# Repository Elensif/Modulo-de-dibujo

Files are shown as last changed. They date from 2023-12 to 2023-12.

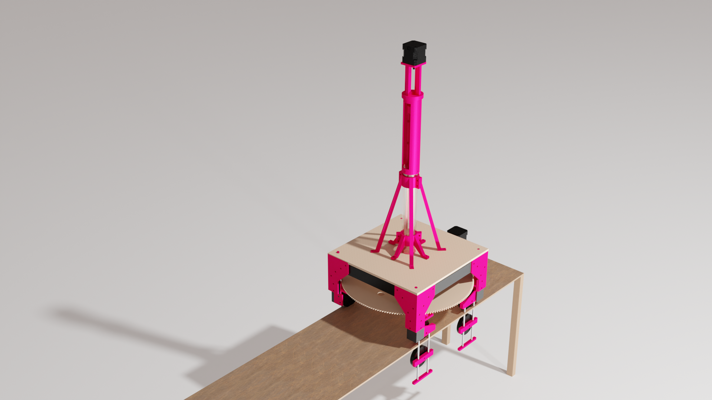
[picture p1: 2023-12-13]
Modelos 3D/Fotografías/1. Diseño prototipo.png

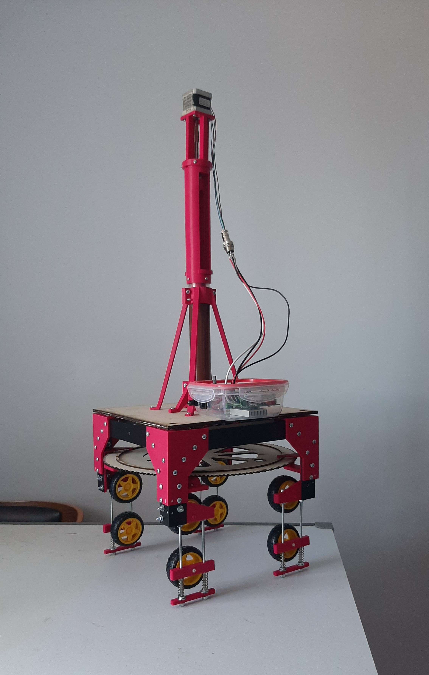
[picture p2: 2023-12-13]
Modelos 3D/Fotografías/2. Prototipo armado.jpg

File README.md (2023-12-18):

# Módulo de dibujo

El siguiente repositorio corresponde a los archivos diseñados para el armado del módulo. Las piezas 3D se imprimieron en su mayoría en una Ender 5 utilizando filamento de PLA. Los archivos de DWG son dibujos realizados en Autocad para ser cortados con láser en terciado de 3mm.

Se utilizaron perfiles de aluminio de 32x32 para armar el chasis del módulo.
El extrusor se conecta mediante una manguera de silicona food grade de 8mm de diámetro interior y 11mm de diámetro exterior a la boquilla del disco.
Para el relleno del extrusor se utilizó una ganache de 200gr. de chocolate 54%, 200gr. crema de leche y 50gr. glucosa. Se utiliza a temperatura ambiente, alrededor de 20.5°C; se recomienda que tenga un par de horas de reposo después de haberla hecho para su uso.
Dependiendo del ancho de las ruedas depende la ubicación de la perforación circular del disco por donde pasa la boquilla/lápiz, por lo que esta deberá moverse hacia el centro si la rueda es muy ancha para que esta no aplaste el dibujo.
El diseño está hecho para un tubo de acrílico de 40mm de diámetro exterior y 34mm interior.

Para la caja electrónica se utilizó la librería de: https://hackaday.io/project/183713/instructions
La velocidad máxima en el código utilizado para el motor es de 200.

Excel de componentes del proyecto: 
https://docs.google.com/spreadsheets/d/1XOzpoQ05eOA92ipmq-vIG3SNlGOVWvsAdQOaHhamvO8/edit?usp=sharing

Sobre el proyecto: 
https://wiki.ead.pucv.cl/M%C3%B3dulo_perform%C3%A1tico_de_un_dibujo_comestible

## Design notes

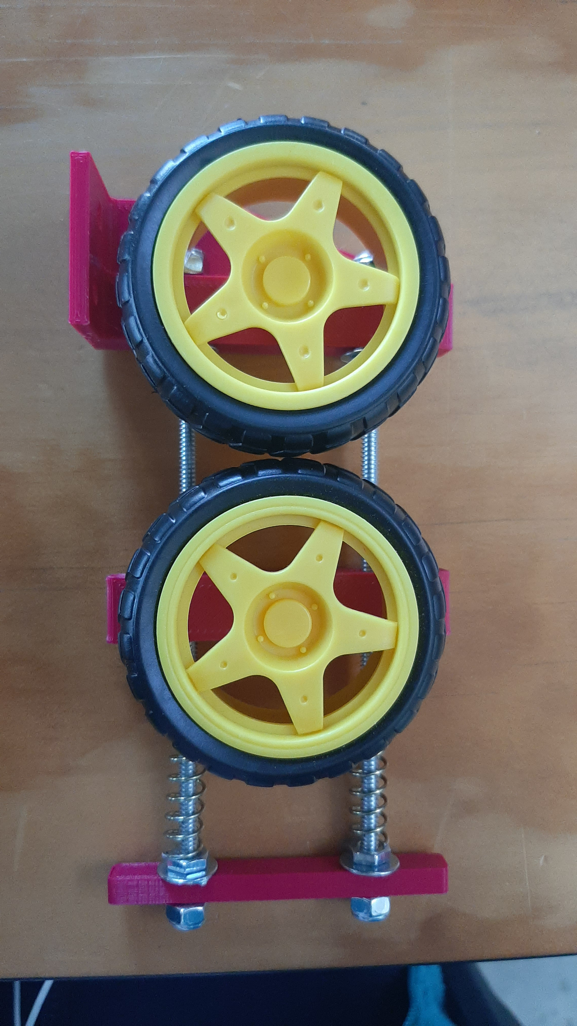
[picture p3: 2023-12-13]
Modelos 3D/Fotografías/5. Ruedas.jpg

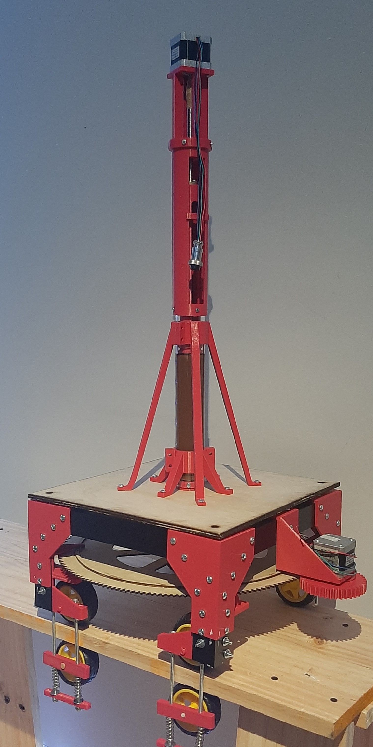
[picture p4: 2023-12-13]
Modelos 3D/Fotografías/3. Prototipo montado.jpg

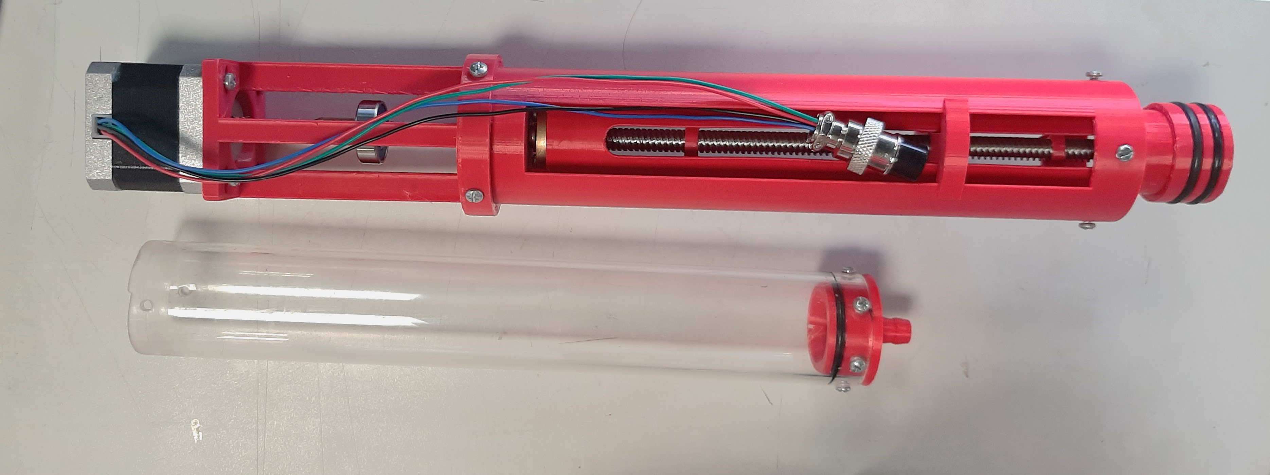
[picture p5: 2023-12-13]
Modelos 3D/Fotografías/7. Extrusor.jpg

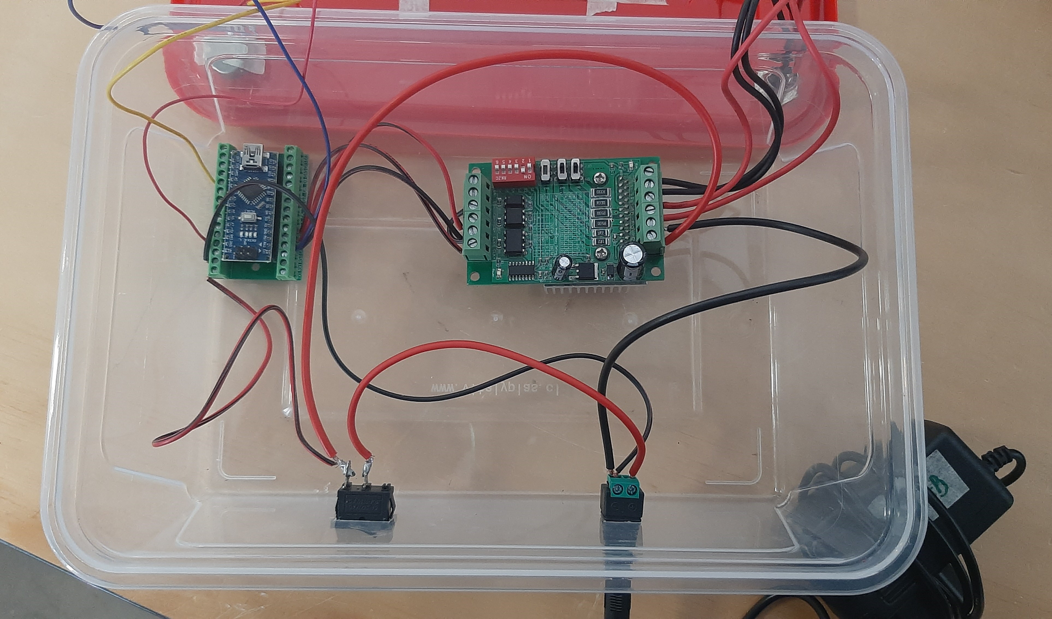
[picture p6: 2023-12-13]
Caja electrónica/Fotografía B.jpg

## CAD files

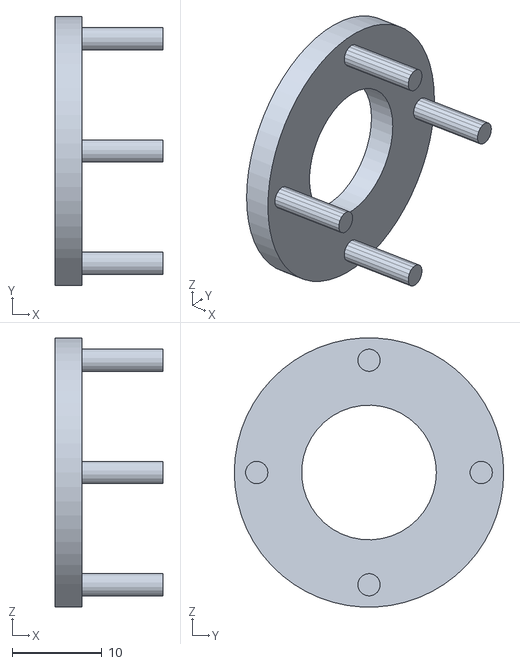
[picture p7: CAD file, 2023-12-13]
Modelos 3D/Extrusor/Boquilla disco/Sujetador boquilla de disco superior.stl
12.0 x 30.0 x 30.0

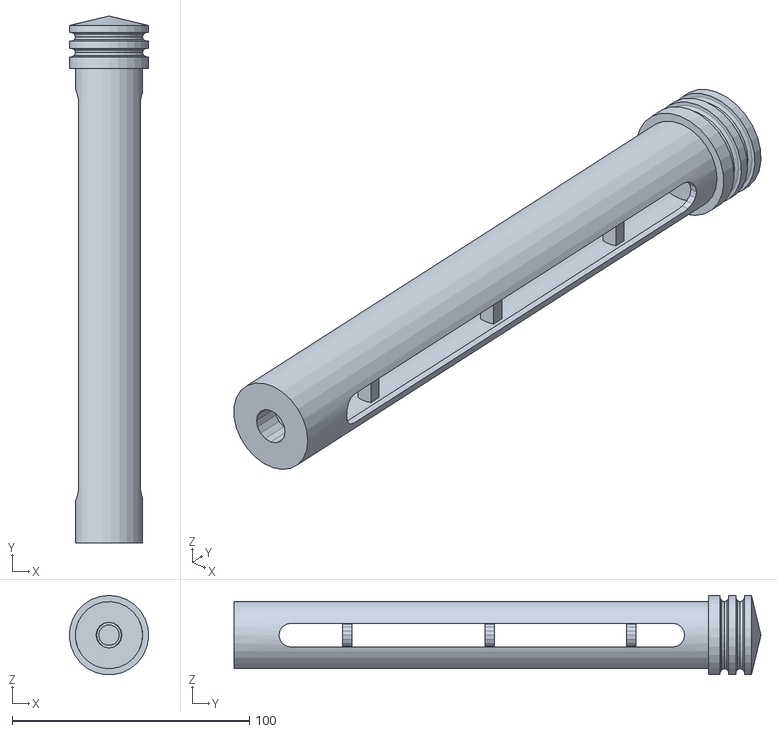
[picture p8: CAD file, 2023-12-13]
Modelos 3D/Extrusor/Pistón.stl
33.4 x 222.2 x 33.4

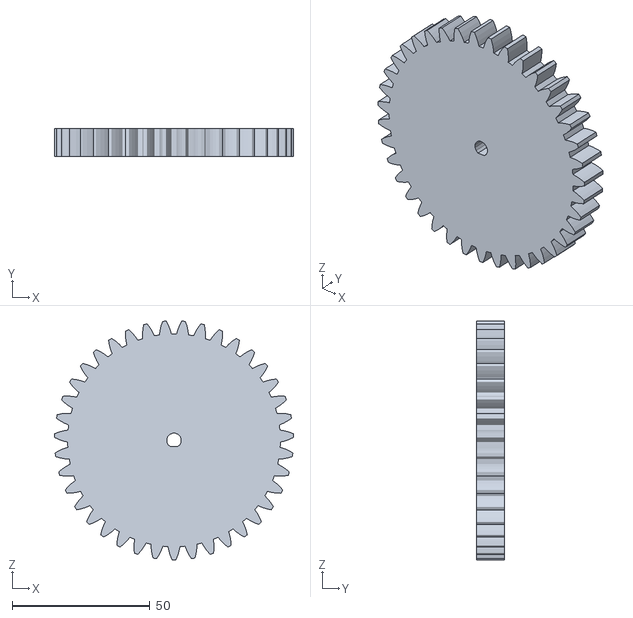
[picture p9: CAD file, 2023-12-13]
Modelos 3D/Módulo/Engranaje motorizado/Engranaje lateral.stl
86.8 x 10.0 x 86.8

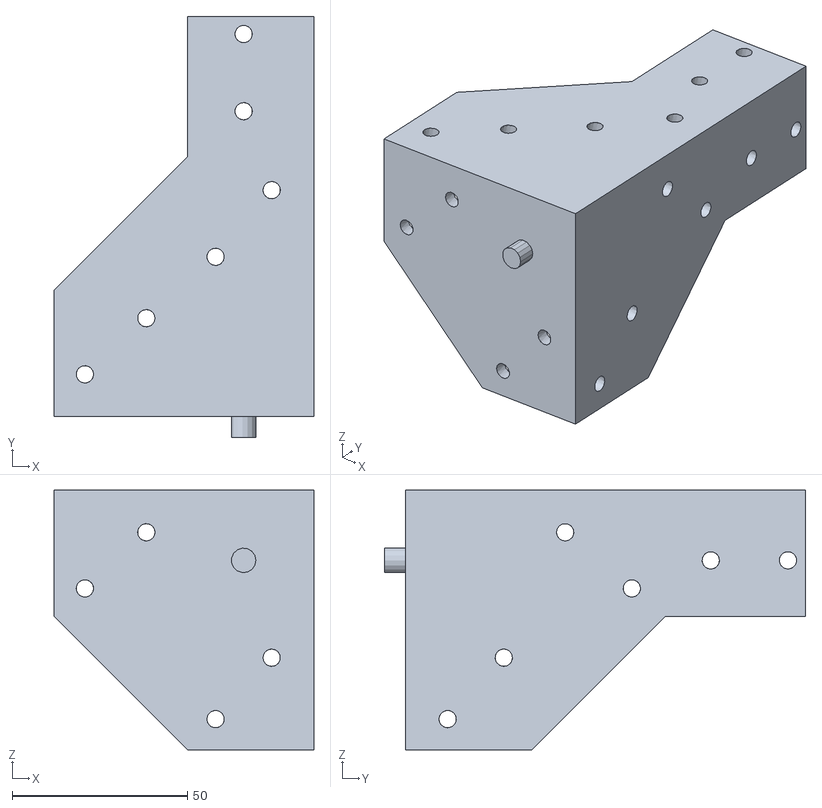
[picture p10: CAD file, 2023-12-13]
Modelos 3D/Módulo/Escuadra esquina.stl
74.0 x 120.0 x 74.0

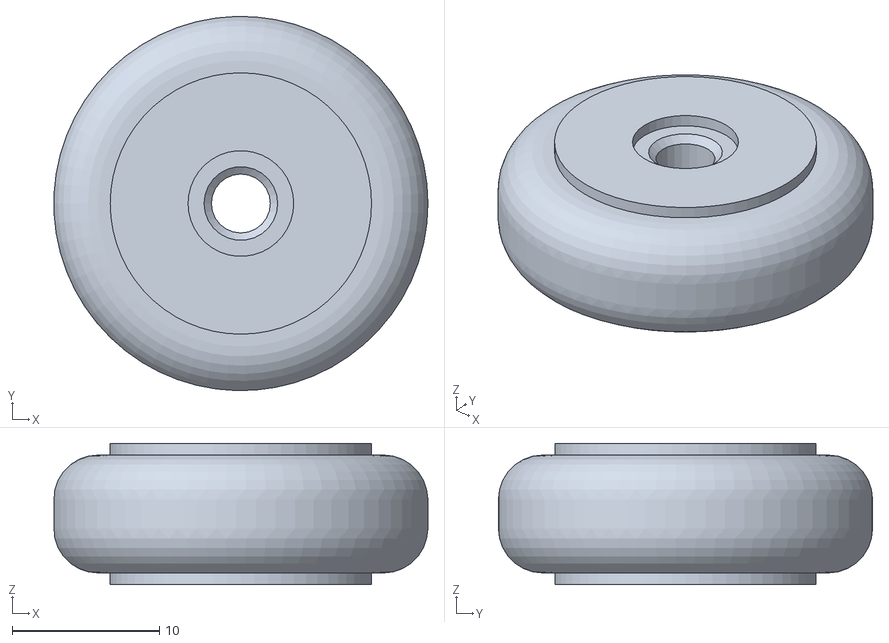
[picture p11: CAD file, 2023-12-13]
Modelos 3D/Módulo/Ruedas disco/Rueda.stl
25.4 x 25.4 x 9.60

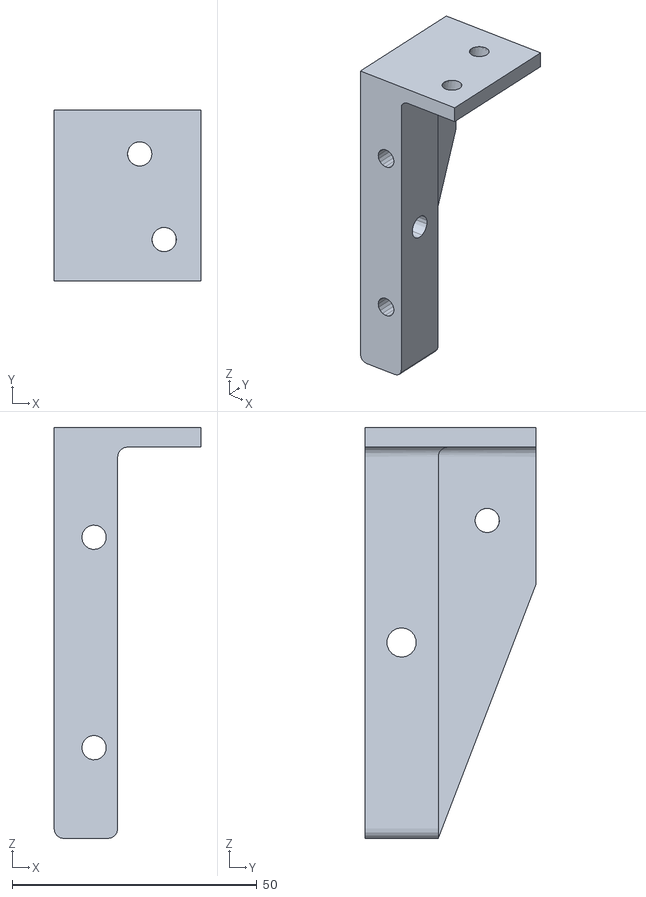
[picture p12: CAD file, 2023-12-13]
Modelos 3D/Módulo/Ruedas módulo/Pieza fija superior A.stl
30.0 x 35.0 x 84.0

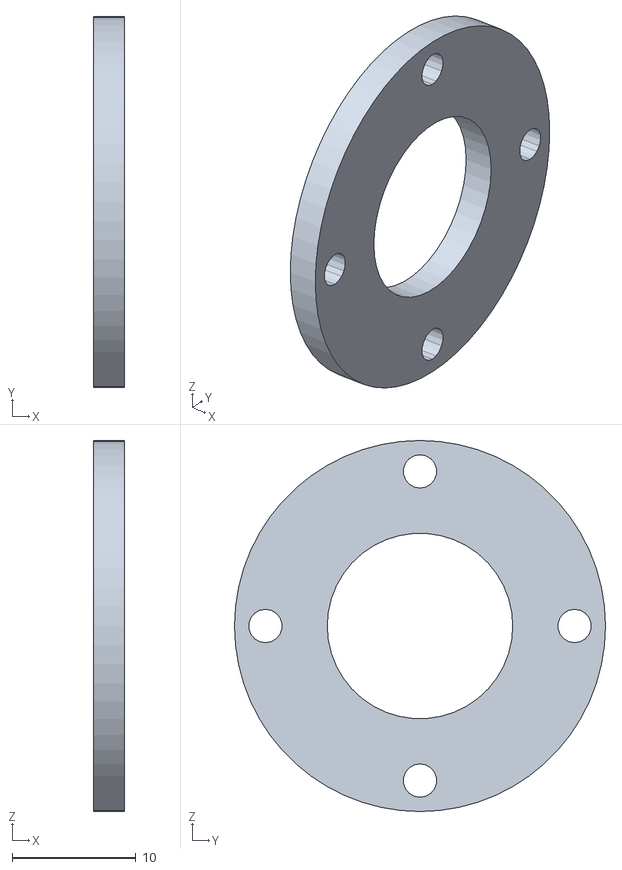
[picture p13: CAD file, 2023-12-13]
Modelos 3D/Extrusor/Boquilla disco/Sujetador boquilla de disco inferior.stl
2.50 x 30.0 x 30.0

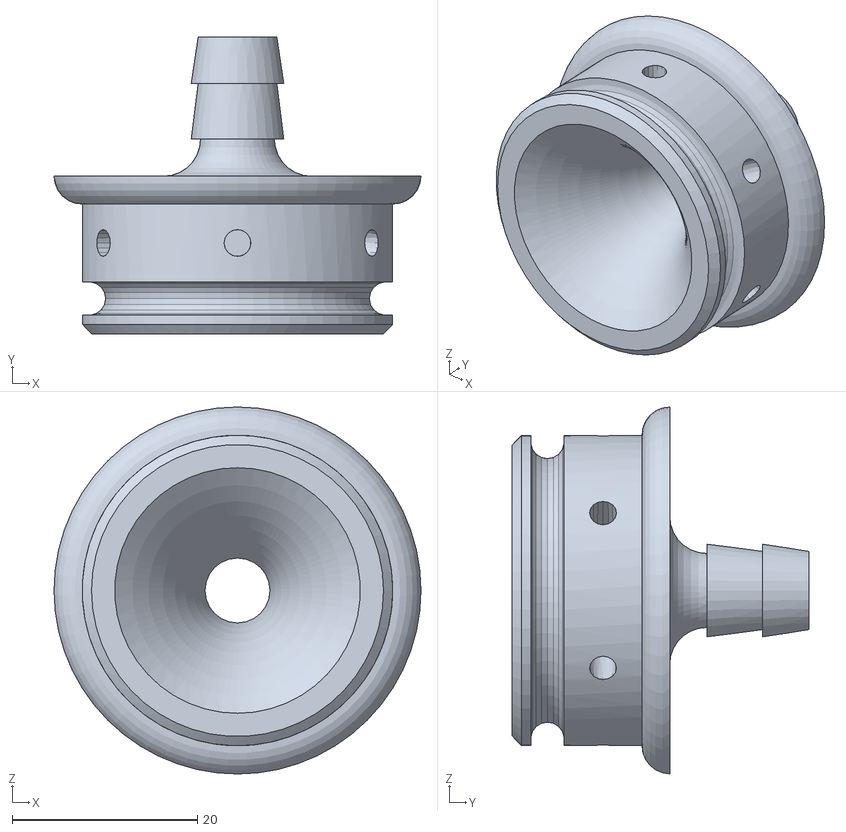
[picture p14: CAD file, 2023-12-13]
Modelos 3D/Extrusor/Boquilla.stl
39.6 x 32.0 x 39.6

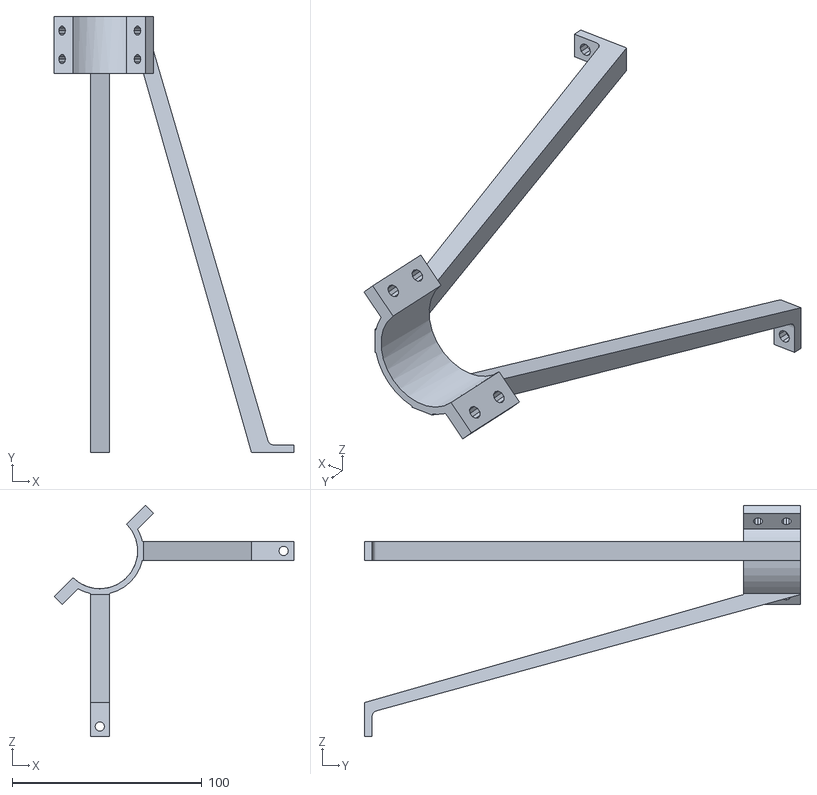
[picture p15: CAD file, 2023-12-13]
Modelos 3D/Módulo/Base superior/Sujetador Extrusor A.stl
126.4 x 230.0 x 122.0

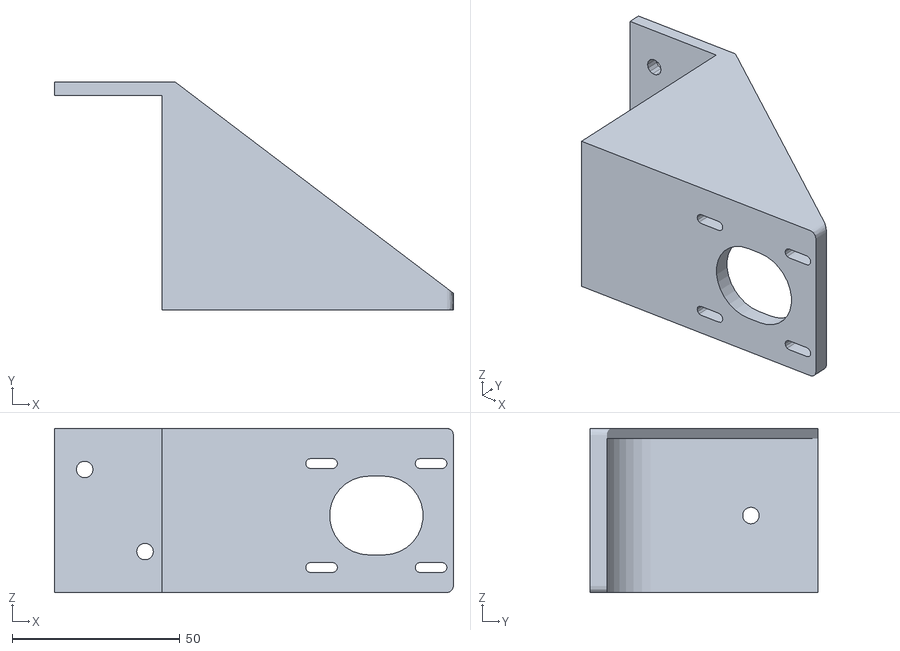
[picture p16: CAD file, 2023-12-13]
Modelos 3D/Módulo/Engranaje motorizado/Soporte motor nema23.stl
119.0 x 68.0 x 49.0

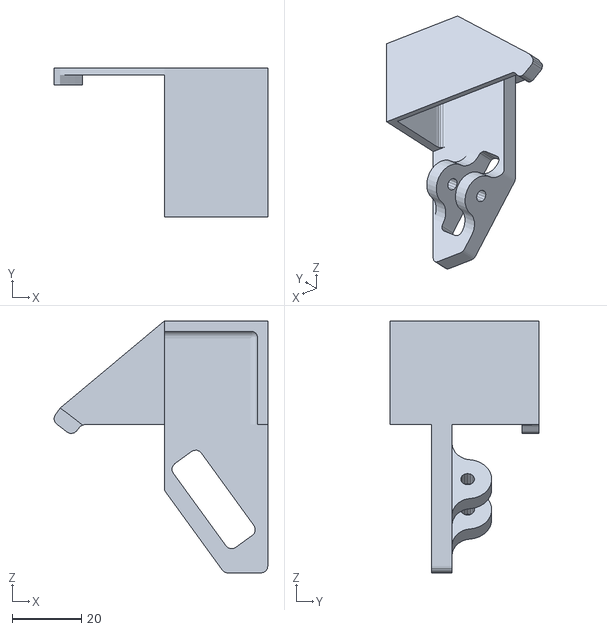
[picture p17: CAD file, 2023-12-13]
Modelos 3D/Módulo/Ruedas disco/Pieza ruedas.stl
61.9 x 43.2 x 73.0

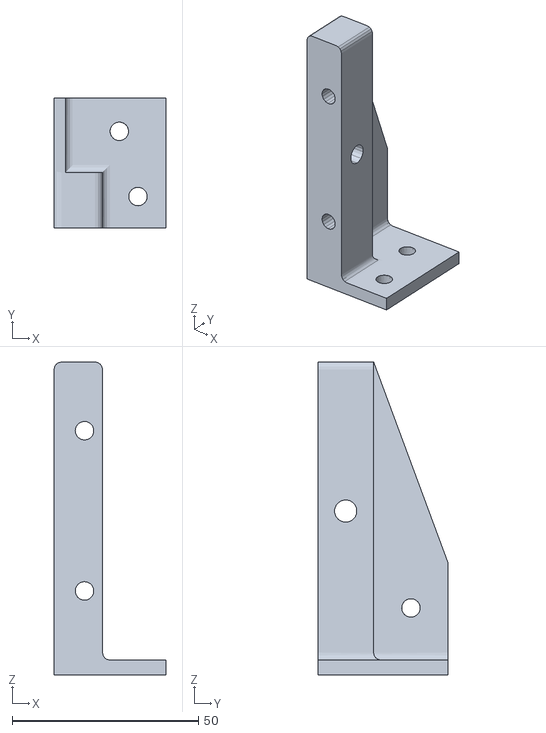
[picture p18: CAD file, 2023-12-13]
Modelos 3D/Módulo/Ruedas módulo/Pieza fija superior B.stl
30.0 x 35.0 x 84.0

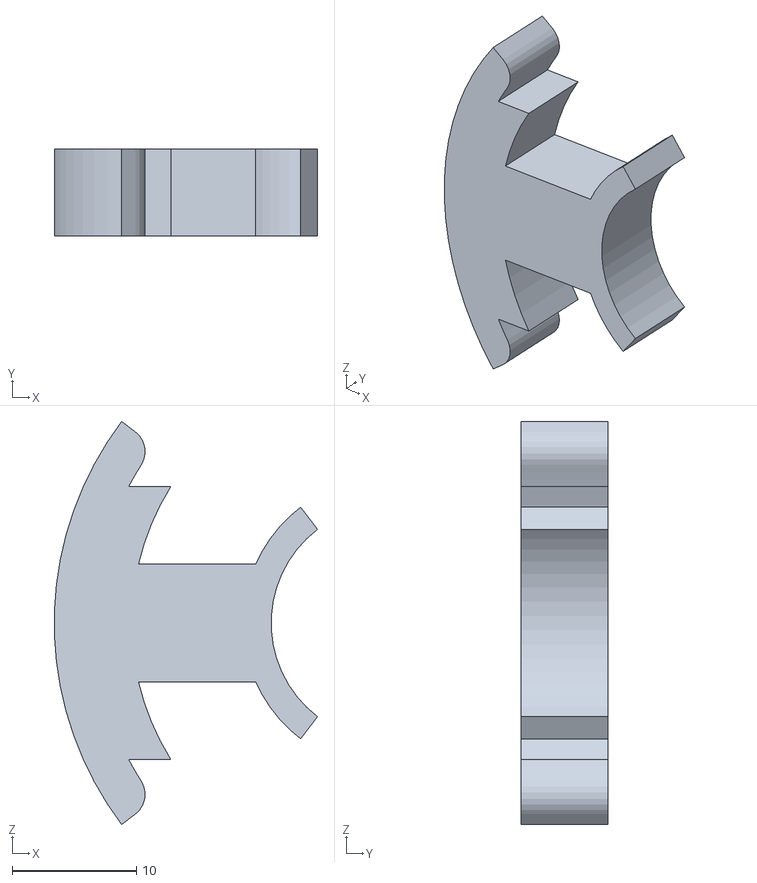
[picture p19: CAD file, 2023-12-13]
Modelos 3D/Extrusor/Alineador pistón-base.stl
21.2 x 7.00 x 32.5

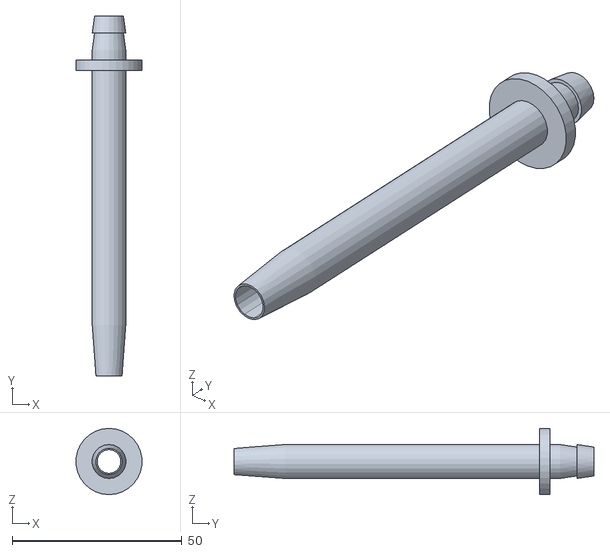
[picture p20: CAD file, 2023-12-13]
Modelos 3D/Extrusor/Boquilla disco/Boquilla de disco.stl
19.4 x 106.0 x 19.5

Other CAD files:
Modelos 3D/Módulo/Base superior/Base.dwg
Modelos 3D/Módulo/Disco/Disco.dwg
Modelos 3D/Módulo/Base superior/Sujetador Extrusor B.stl
Modelos 3D/Módulo/Ruedas módulo/Pieza móvil.stl
Modelos 3D/Extrusor/Base A.stl
Modelos 3D/Extrusor/Base motor Nema17.stl
Modelos 3D/Extrusor/Base motor Nema23.stl
Modelos 3D/Módulo/Ruedas módulo/Pasador ruedas.stl
Modelos 3D/Módulo/Ruedas módulo/Tope inferior.stl

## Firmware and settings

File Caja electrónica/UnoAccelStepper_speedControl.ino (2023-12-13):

/*
   Uno sketch to drive a stepper motor using the AccelStepper library.
   Function runSpeed() is used to run the motor at constant speed. A pot is read to vary the speed.
   Works with a ULN-2003 unipolar stepper driver, or a bipolar, constant voltage motor driver
   such as the L298 or TB6612, or a step/direction constant current driver like the a4988.
   A potentiometer is connected to analog input 0 and to gnd and 5v.

 The motor will rotate one direction. The higher the potentiometer value,
 the faster the motor speed. Because setSpeed() sets the delay between steps,
 you may notice the motor is less responsive to changes in the sensor value at
 low speeds.

 Created 30 Nov. 2009
 Modified 28 Oct 2010
 by Tom Igoe
 12/26/21  Modified to use AccelStepper.  --jkl

 */
// Include the AccelStepper Library
#include <AccelStepper.h>
#include <elapsedMillis.h>

// Define motor interface type
#define motorInterfaceType 1

// Motor Connections (unipolar motor driver)
const int In1 = 8;
const int In2 = 9;
const int In3 = 10;
const int In4 = 11;
// Motor Connections (constant voltage bipolar H-bridge motor driver)
const int AIn1 = 8;
const int AIn2 = 9;
const int BIn1 = 10;
const int BIn2 = 11;
// Motor Connections (constant current, step/direction bipolar motor driver)
const int dirPin = 2;
const int stepPin = 3;

// Creates an instance - Pick the version you want to use and un-comment it. That's the only required change.
//AccelStepper myStepper(AccelStepper::FULL4WIRE, AIn1, AIn2, BIn1, BIn2);  // works for TB6612 (Bipolar, constant voltage, H-Bridge motor driver)
//AccelStepper myStepper(AccelStepper::FULL4WIRE, In1, In3, In2, In4);    // works for ULN2003 (Unipolar motor driver)
//AccelStepper myStepper(AccelStepper::DRIVER, stepPin, dirPin);           // works for a4988 (Bipolar, constant current, step/direction driver)
AccelStepper myStepper(motorInterfaceType, stepPin, dirPin);

elapsedMillis printTime;

const int maxSpeedLimit = 30.0;  // set this to the maximum speed you want to use.

void setup() {
  Serial.begin(9600);
  // set the maximum speed and initial speed.
  myStepper.setMaxSpeed(maxSpeedLimit); 
  myStepper.setSpeed(maxSpeedLimit/5.0);    // initial speed target
}


void loop() {
    float mSpeed;
  if (printTime >= 1000) {    // print every second
    printTime = 0;
    mSpeed = myStepper.speed();
    Serial.print(mSpeed);
    Serial.print("  ");
    Serial.println(myStepper.currentPosition());
  }
  // read the sensor value:
  int sensorReading = analogRead(A1);
  // map it to a the maximum speed range
  int motorSpeed = map(sensorReading, 0, 1023, 5, maxSpeedLimit);
  // set the motor speed:
  if (motorSpeed > 0) {
    myStepper.setSpeed((float)motorSpeed);
  }
  myStepper.setPinsInverted(true);
  myStepper.runSpeed();
}
